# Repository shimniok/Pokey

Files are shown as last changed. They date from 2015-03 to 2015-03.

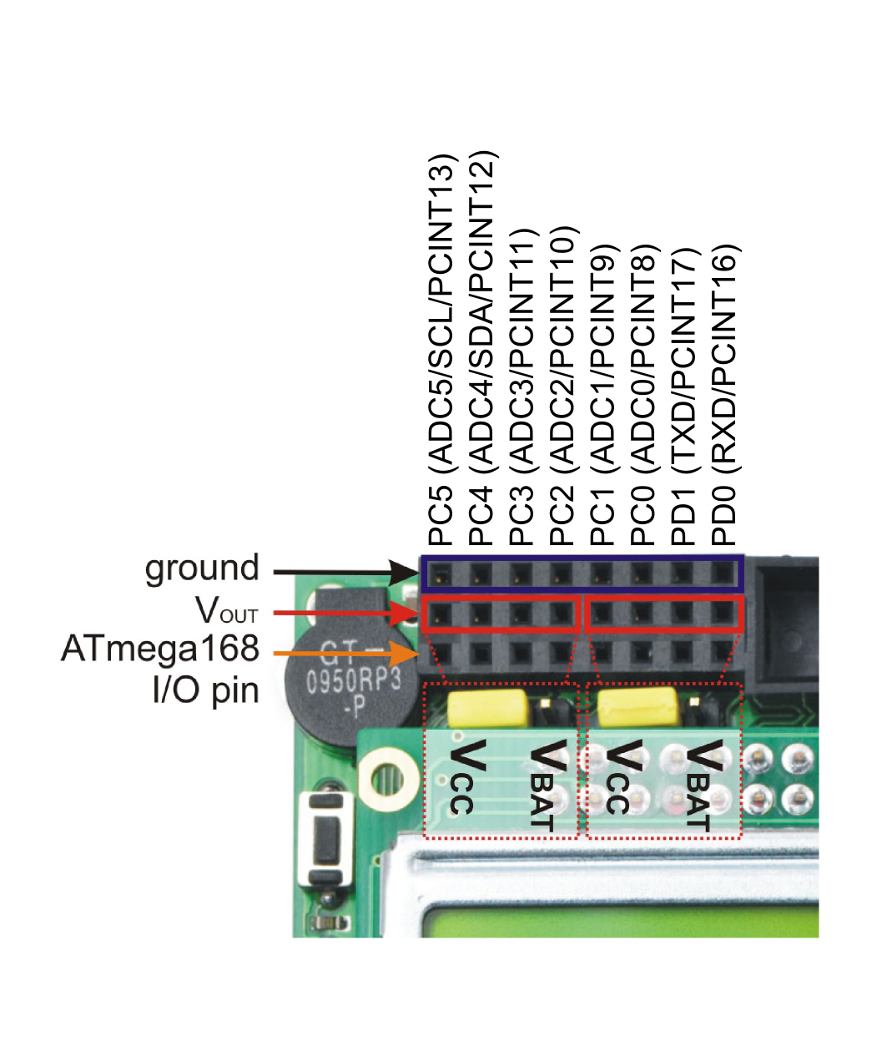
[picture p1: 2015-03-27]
LV168_Pinout.png

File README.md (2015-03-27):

# Pokey

Pokey is the firefighting robot I entered into the 2007 Front Range Robotics Firefighting Challenge. It lost. But I've been
revising and improving it over the years.

I've also been using it to demonstrate robotics to lots and lots of children and quite a few adults at various robotics
expos like Robots At The Hangar, Denver Mini Maker Faire, and so on.  The kids love it. :)

# Directories

 * ff - is the main code base that I'm writing from scratch
 * encoders - scratch area for me playing with encoders
 * simple-test - is a simple led blinky, mostly for me playing
 * demo - some basic demonstration functionality, mostly for me playing

# Details

The basic Pokey Design uses a Pololu Orangutan LV168 with ATmega168 onboard. I'm using the old libpololu-avr library.

## Pinout

See LV168_Pinout.png

 * PC0 (PCINT8) - Right Encoder
 * PC1 (PCINT9) - Left Encoder

## Drivetrain

The robot has differential drive, using Tamiya 70168 Double Gearbox with low voltage Mabuchi motors.

## Chassis

The chassis is made of 1/4" funiture-grade plywood (or if I update it, hobby-grade plywood)

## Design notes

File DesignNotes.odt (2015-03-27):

Pokey

Firefighting robot for Trinity-style competition.

Ideally would like to upgrade, simplest, shortest path, to get the robot working well

Flame detection via combo of IR LEDs (the ones that are best for Trinity) and Gameboy B&W camera running at hopefully 30fps and accessible via I2C

Navigation – ??

Wall avoidance – ??

- Probably Sharp IR sensors w/ A2D adapters.
- Dual wheel encoders – could easily do this via I2C to an ATtiny reading pulses.
- I2C to GB camera
- Ideally logging/telemetry/control via Xbee or other radio.
- Dual floor sensors, could also run off A2D
- Fan control (servo)
- Differential drive motor control (dual motors)

Right now using Orangutan LV-168 which has ideal motor drivers but ATmega168 may be a bit light on memory if things get too complicated. I ran out of memory last time. Although I can probably significantly optimize the code this time around. I could use an Baby Orangutan ATmega328P. Lots more pins. Need a baseboard, probably.

- Status LCD
  - I2C backpack
- Flame Detection
  - GB cam via I2C
  - Need to run GBcam at 10-30fps
- Motor control
  - Differential drive
  - Dual wheel encoders for feedback
- Direction control
  - Wheel encoders
  - Gyro ?
- Flame extinguishing
  - RC plane propeller and motor/gearbox
  - Fan controller – ESC?
  - Fan deployment? Or static mount?
- Wall avoidance/following
  - Sharp sensors?
  - On rotating array?
  - Mount sharp appropriate distance—how?
  - VCNL 4000 I2C, 10-150mm range, Adafruit, Sparkfun
  - Plain old IR LED/Phototrans pair?
- Command, control, and telemetry
  - Xbee?
  - Wifi?
  - Other RF modules?
- Power
  - BEC from ESC that runs the fan?
  - Separate ESC (Pololu 3.5A?)
  - 2S LiPo could run ESC/Fan/BEC versus mult batteries, boost regulators, etc., run motors at 5V and/or find 5V versions of the motors.

Would an RTOS be of any value?

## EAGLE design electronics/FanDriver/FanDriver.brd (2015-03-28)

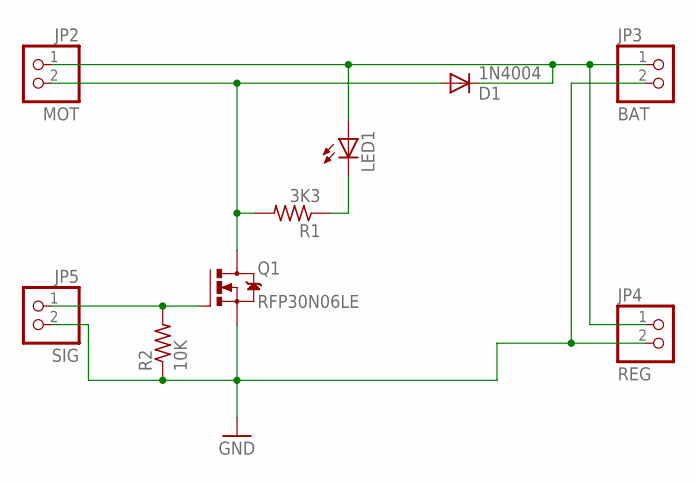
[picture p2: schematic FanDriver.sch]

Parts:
D1: 1N4004; DO41-10
JP2: MOT; 1X02-S
JP3: BAT; 1X02-S
JP4: REG; 1X02-S
JP5: SIG; 1X02-S
LED1: LEDCHIPLED_1206; CHIPLED_1206
Q1: RFP30N06LE; TO220BV
R1: 3K3; R0603
R2: 10K; R0603

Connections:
GND: JP3.2, JP4.2, JP5.2, Q1.S, R2.1
M2: D1.A, JP2.2, Q1.D, R1.2
unnamed: LED1.C, R1.1
SIG: JP5.1, Q1.G, R2.2
VBAT: D1.C, JP2.1, JP3.1, JP4.1, LED1.A

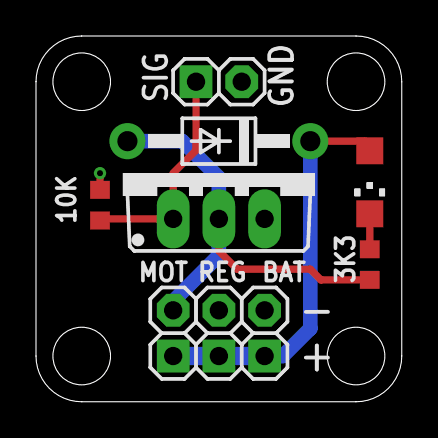
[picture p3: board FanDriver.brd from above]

Board: 2 copper layers, 20.3 x 20.3 mm, 9 parts (0 on the bottom side), 5 nets.

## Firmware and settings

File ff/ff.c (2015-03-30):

#include <pololu/orangutan.h>
#include "gbcam/camcom.h"
#include "I2C_master.h"

void fan_init(void);
void fan_on(void);
void fan_off(void);
void encoder_init(void);

unsigned int eright = 0; // encoder right counter
unsigned int eleft = 0;  // encoder left counter

int main()
{
	unsigned int t;

	I2C_init();

	clear();
	lcd_goto_xy(0, 0);
	print("Pokey   ");

	fan_init();
	delay_ms(1000);

	lcd_goto_xy(0, 1);
	print("fan on  ");
	fan_on();
	delay_ms(1000);

	lcd_goto_xy(0, 1);
	print("fan off ");
	fan_off();
	delay_ms(1000);

	// Motor test
	lcd_goto_xy(0, 1);
	print("motors  ");

	for (t = 0; t < 2000; t++) {
		if (t < 500 || t >= 1500) {
			set_motors(50, -50);
		} else {
			set_motors(-50, 50);
		}
		delay_ms(1);
	}
	set_motors(0, 0);

	lcd_goto_xy(0, 1);
	print("ready   ");

	while(1) {
		red_led(0);
		green_led(1);

//		delay_ms(100);

		I2C_start(TWI_CAMERA, 0); // write register
		I2C_write(CAM_COM_GET_OBJECTS); // command
		I2C_stop();
		delay_ms(100);
		I2C_start(TWI_CAMERA, 1); // read values
		uint8_t o = I2C_read(I2C_NACK);
		I2C_stop();

		if (o == 0) {
			lcd_goto_xy(0, 1);
			print_hex(0);
		}

		while(o--) {
			I2C_start(TWI_CAMERA, 1);
			uint8_t left   = I2C_read(I2C_ACK); // ack
			uint8_t top    = I2C_read(I2C_ACK); // ack
			uint8_t right  = I2C_read(I2C_ACK); // ack
			uint8_t bottom = I2C_read(o); // nack if last object, else ack
			lcd_goto_xy(0, 1);
			print_hex((left + right)>>1);
			I2C_stop();
		}

		red_led(1);
		green_led(0);
		
		delay_ms(100);
	}

	return 0;
}

/**
 * Prepare fan control
 */
inline void fan_init() {
	PORTC &= ~(1<<PC2);
	DDRC |= (1<<PC2);
}

/**
 * Run the fan on PC2
 */
inline void fan_on() {
	PORTC |= (1<<PC2);
}

inline void fan_off() {
	PORTC &= ~(1<<PC2);
}
	

/**
 * Initialize dual encoder pins using PC0, PC1, set up interrupts
 */
inline void encoder_init() {
	PCMSK1 |= (1<<PCINT8)|(1<<PCINT9);		// Enable PC0 (PCINT8), PC1 (PCINT9)
	PCICR |= (1<<PCIE1);					// Enable PCINT1 interrupts
	DDRC &= ~((1<<PC0)|(1<<PC1));			// Ensure PC0, PC1 are inputs
	eright = eleft = 0;							// Reset counters
	sei();
}

/**
 * Interrupt handler for PCINT8/PCINT9
 */
ISR(PCINT1_vect) {
	static uint8_t last = 0;
	static uint8_t change = 0;
	
	change = PINC ^ last;
	
	if (change & (1<<PC0)) {
		eright++;
	}
	
	if (change & (1<<PC1)) {
		eleft++;
	}
	
	last = PINC;
}

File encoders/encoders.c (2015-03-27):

#include <pololu/orangutan.h>
#include <util/delay.h>

void encoder_init(void);

unsigned long e0, e1;

int main()
{
	clear();
	lcd_goto_xy(0, 0);
	print(" Pokey");

	encoder_init();

	while (1) {
		lcd_goto_xy(0, 0);
		print_long(e0);
		lcd_goto_xy(0, 1);
		print_long(e1);
		_delay_ms(20);
	}

	return 0;
}

/**
 * Initialize dual encoder pins using PC0, PC1, set up interrupts
 */
void encoder_init() {
	PCMSK1 |= (1<<PCINT8)|(1<<PCINT9);		// Enable PC0 (PCINT8), PC1 (PCINT9)
	PCICR |= (1<<PCIE1);					// Enable PCINT1 interrupts
	DDRC &= ~((1<<PC0)|(1<<PC1));			// Ensure PC0, PC1 are inputs
	e0 = e1 = 0;							// Reset counters
	sei();
}

ISR(PCINT1_vect) {
	static uint8_t last = 0;
	static uint8_t change = 0;
	
	change = PINC ^ last;
	
	if (change & (1<<PC0)) {
		e0++;
	}
	
	if (change & (1<<PC1)) {
		e1++;
	}
	
	last = PINC;
}

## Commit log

2015-03-27 Implemented ack parameter for write (master); implemented I2C automatic write/read bit addressing; converted args to const
2015-03-27 Initial commit for demo, encoders (testing), simple-test
2015-03-27 added encoder handler, variables, init
2015-03-27 moved servo/esc controller to C2, restored initialization
2015-03-28 initial version of fan driver board
    [FanDriver.brd, FanDriver.sch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]
2015-03-30 converted code to use plain mosfet vs. esc for fan control
